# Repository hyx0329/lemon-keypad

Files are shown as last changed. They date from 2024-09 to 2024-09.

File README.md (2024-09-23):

# Lemon Keypad

> [English](README.md), [简体中文](README.zh.md)

A macro pad/mechanical keyboard based on RP2040. This is *probably* an *improved* version of the [original adafruit version](https://learn.adafruit.com/qtpy-lemon-mechanical-keypad-macropad/).

This is a simple 6-key keypad. What makes it different is that the main program is written in async Python(CircuitPython).
With python's flexibility, a lot can be done with ease with this keypad, on demand.

<!-- TOC depthfrom:2 -->

- [Project folders and their content](#project-folders-and-their-content)
- [Software implementation](#software-implementation)
    - [implemented](#implemented)
    - [potentials left to users](#potentials-left-to-users)
- [Hardware components](#hardware-components)
- [The real thing: close looks](#the-real-thing-close-looks)

<!-- /TOC -->

This repo consists of shell CAD(FreeCAD & STL), PCB design files(KiCAD), and software(CircuitPython project).

I found myself lack the capability/motivation to productize it, so I decided to publish it and hope it last longer, inspiring others.

## Project folders and their content

- CAD: stores CAD files for shell
- lemon-rp2040-keypad: kicad project file
- software: CircuitPython project directory

## Software implementation

### implemented

- keyboard keys input
    - including consumer control keys
- mouse input
- complex key actions
    - key combinations
    - key sequences
    - tap dance
    - layer switch
    - delay
- custom function
    - gyro mouse(built-in example)
    - level gauge(built-in example)

### potentials left to users

- random number generator
- Whack-a-Mole
- a BIG button used up-side-down
- password storage(with pin protection)
- ducky pad
- etc.

## Hardware components

- RP2040
- LSM6DS3TRC inertial module(gyro & accelerometer)
- WS2812 * 6
- MX switch hot-swappable socket
- Kailh BOX white switches
- WB25Q128JVSQ flash memory
- AMS1117-3V3
- misc passive components

## The real thing: close looks

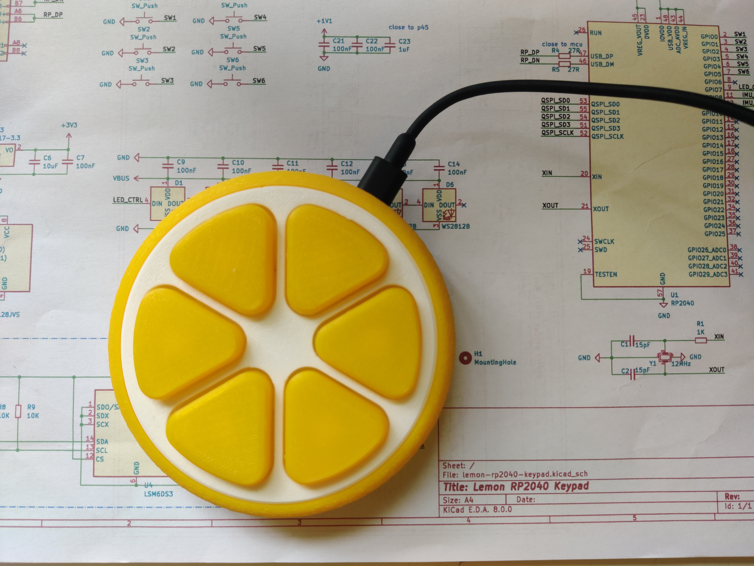
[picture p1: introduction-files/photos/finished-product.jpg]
Finished lemon keypad


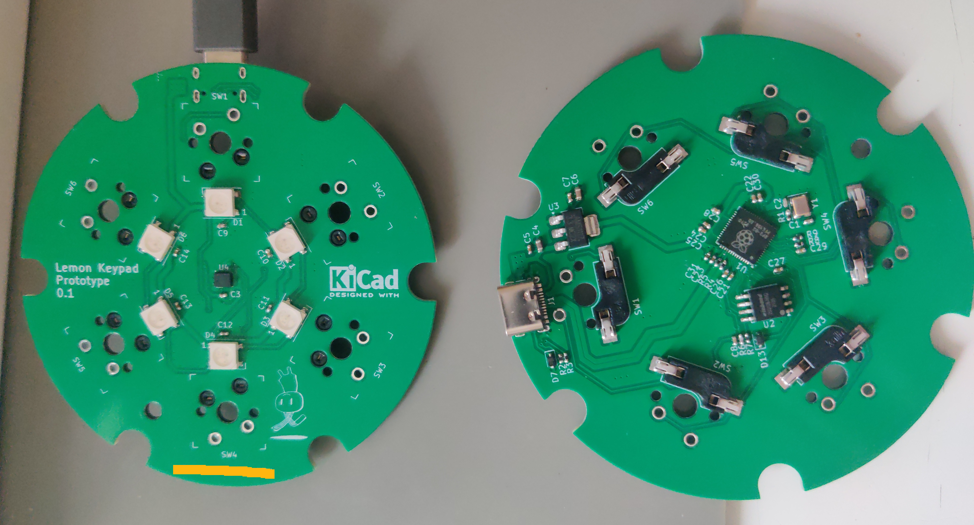
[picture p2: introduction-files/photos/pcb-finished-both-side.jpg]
PCB photos, both sides


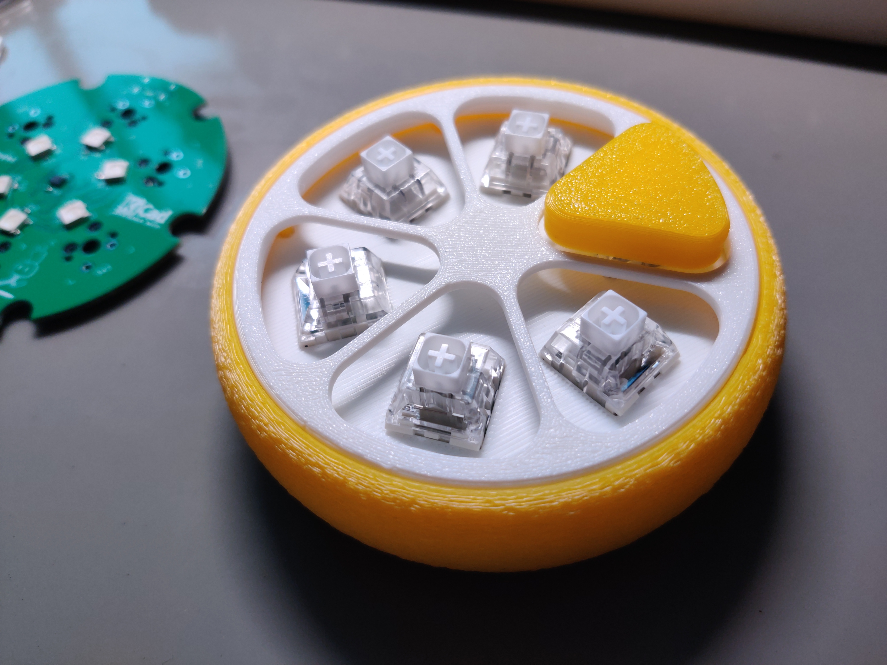
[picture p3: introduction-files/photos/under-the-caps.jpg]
under the key caps


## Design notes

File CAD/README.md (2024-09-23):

## Shell CAD

The design is remixed from the original adafruit version. What reused are:

- key switch layout
- key cap

What modified/redesigned are:

- main body
    - make it a one-piece object for easier 3D printing and assembling
    - adapt to custom PCB shape
- plates

*WARNING: If you want to replicate my work, use the STL models(tested), NOT the FreeCAD file! They may not synchronized!*

## Assembly notes

- The PCB is mounted with one optional M3 screw.
- The switch plate is secured by those MX switches.
- The top plate is secured through interference fit.

## 3D view

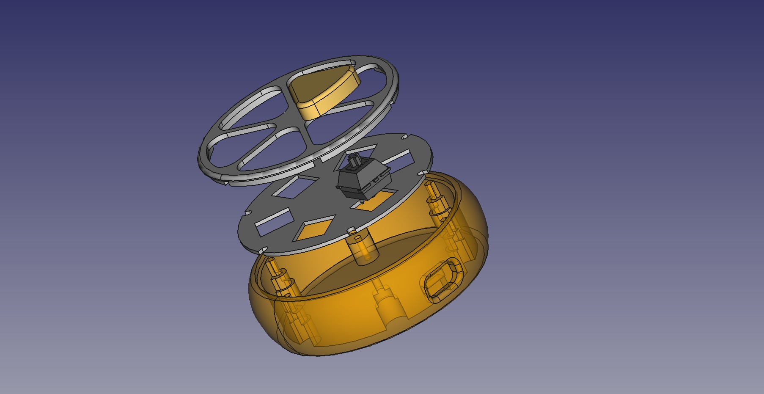
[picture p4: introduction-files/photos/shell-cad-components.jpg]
shell components, PCB not shown


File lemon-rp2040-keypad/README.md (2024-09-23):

# Lemmon Keypad KiCAD Project

Have fun! :D It's just a prototype and design issues may exist, despite I did verify the design with the real thing.

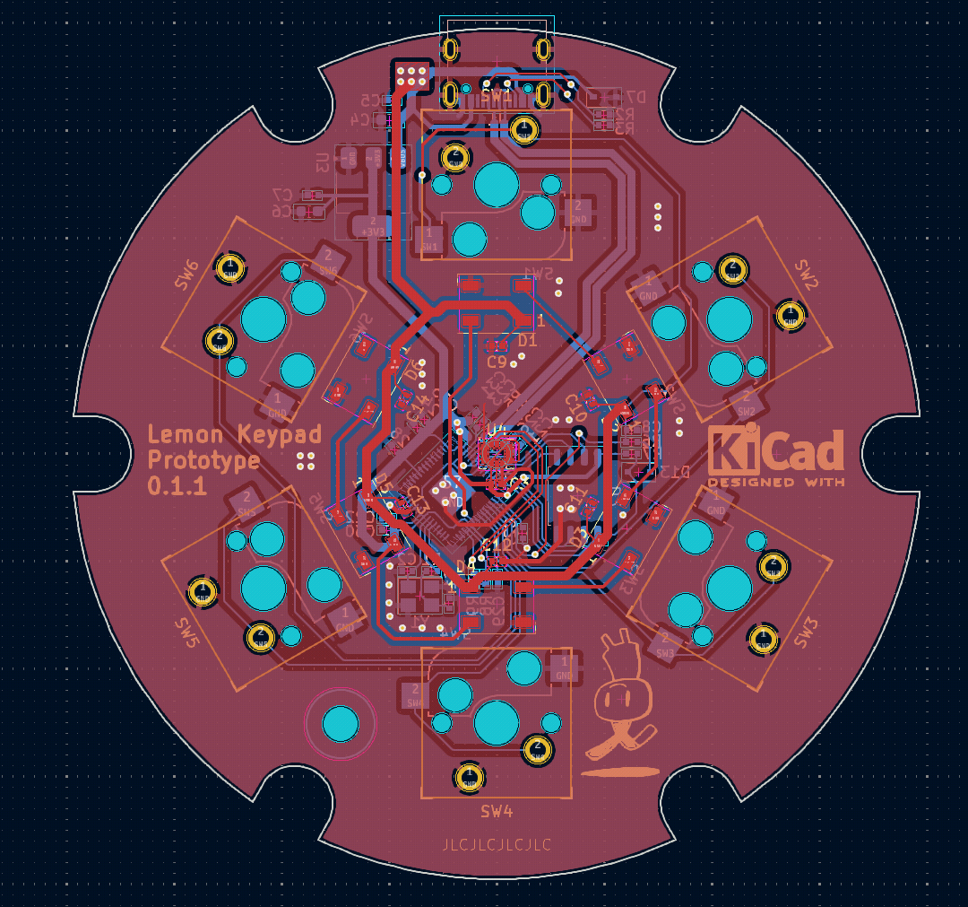
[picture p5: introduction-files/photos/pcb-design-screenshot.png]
pcb design screenshot


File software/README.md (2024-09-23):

# Software part for lemon keypad

Here is the program for lemon keypad running on top the CircuitPython firmware.

Using any Pico compatible cpy firmware variant is OK.

Aha! It's not KMK, but an original multi-layer keyboard implementation :D

## Quick package deploy

1. Install circup and ensure a good internet connection
2. Run the script with target folder as parameter: `./scripts/distribute.sh distribution`

Then the full distributable program package is the `distribution` folder.

## User documentation

Currently only zh-cn available.

## Possible flaws

- Not support key matrix natively, for it's using keypad directly without a mapping matrix.
  But it should be easy to implement.
- Not support bluetooth hid interface, need bt hid wrapper.
- Part of multi-layer support is not designed to be robust/not fully tested,
  so it may be not stable with too many/particular layer switch.

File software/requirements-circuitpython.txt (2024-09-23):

# for CircuitPython only
neopixel
adafruit_hid
adafruit_logging
asyncio
adafruit_lsm6ds

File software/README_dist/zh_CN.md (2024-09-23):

# Hi~ 你收到了一个柠檬键盘！

这份文档将介绍柠檬键盘的预装功能和修改方法。在通读这份文档后，你应该就明白如何进入安全模式、解除模拟U盘写保护，进而修改键盘功能了。

为什么默认加写保护？这不得防止杀毒软件把程序删光了。

还是建议先备份一下程序。

## 键盘硬件简介

这个设备是一个基于RP2040开发的可编程键盘。预装功能的介绍见下一节。

- 固件基于CircuitPython
    - 预载了一份功能完善的实例程序
- 硬件组件包括：
    - 树莓派RP2040微处理器（MCU，或者说CPU）
    - 6个WS2812全彩LED
    - 6个凯华BOX白轴（热插拔，可更换）
    - 1个LSM6DS3TRC 6轴姿态传感器（3轴陀螺仪、3轴加速计）
    - 16MB NOR Flash存储器（大概能放不少程序/文本）

可以把这个键盘当作一个宏键盘，实现各种特殊功能。程序采用Python编写，门槛较低，修改起来也很容易。

## 预装功能

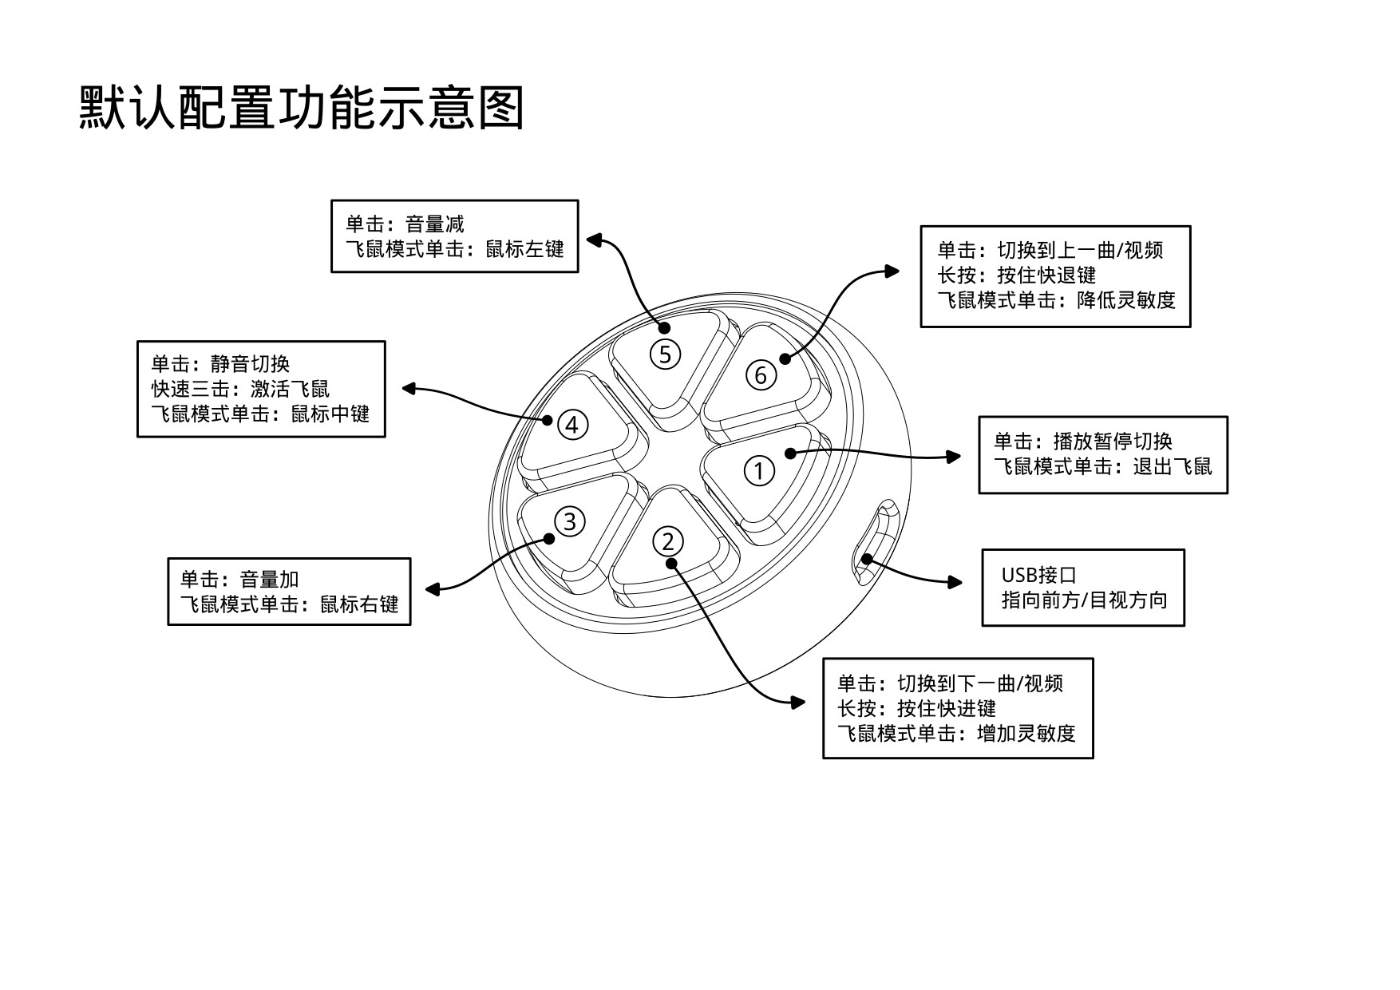
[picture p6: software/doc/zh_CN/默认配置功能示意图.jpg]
默认配置功能示意图


先说明按键顺序：USB口指向的按钮算1号，面向按钮，顺时针方向将各个按钮标记为1～6。彩色LED的编号也是如此。需要注意的是，虽然此处说明的序号从1开始，**但程序内部处理按键和LED所用的编号均从0开始**。

- 多媒体键盘，按键1到6的功能依次为：
    - 按键1：播放/暂停
    - 按键2：短按切换下一曲，长按快进
    - 按键3：音量提高
    - 按键4：静音切换，快速连按3下进入飞鼠模式
        - 飞鼠模式，单击按键1退出
        - 按键5、4、3依次为鼠标左键、中键、右键
        - 按键6、1、2依次为增加灵敏度、退出、降低灵敏度
    - 按键5：音量降低
    - 按键6：短按切换上一曲，长按快退
- 安全模式
    - 插上USB前按住除1号按钮外任意3个或以上按钮，直至所有LED显示为绿色，即进入安全模式
        - 安全模式下程序将不再运行 `boot.py`、`code.py` 中的代码，而运行 `safemode.py`。通常情况下，存放程序的模拟U盘将显示出来。
    - 安全模式为软件功能，在修改预载程序（`boot.py`和`safemode.py`）后不保证有效。
- 刷机模式
    - 按住按钮1再插上USB，可进入USB刷机模式，可以写入UF2格式的固件，一般用不到
    - 刷机模式为微处理器（RP2040）自带功能，在设备未故障时均可生效

通过修改键位图，可以按需实现多种宏功能。

- 支持多层键位图
- 支持定义点击、长按、组合键、序列按键、自定义函数等多种功能
- 放个英文字符串，能直接一口气敲出来
    - 模拟键盘采用美式布局，输出字符串其实只是自动按对应按键

## 修改功能前必读

可以先在 `code.py` 中参考示例修改键位图。亦可依次参考 `键位图示例` 文件夹中的3种键位图配置示例。预先整理好的普通键码可以在 `lib/lemon_keypad/keycode_helper.py` 中查找。按键功能类型可参阅 `软件详细说明/按键功能类型.md`，那是一个Markdown格式的普通文本文件（txt）。

`settings.toml` 是一个全局配置文件，支持字符串作为键、字符串或整数为值，其中的值可采用 `os.getenv("key_name")` 的方法获取。预装配置里提供了配置示范、记录了IMU加速度补偿值。

## 深度修改提示

在做出较复杂的修改前，建议先阅读 `boot.py`、`code.py`、`safemode.py` 程序文件，全部的键位图示例，了解键盘主程序的基本设计。

## 参考点子

- （伪）随机数生成器（也确实有办法做成真随机，参考pico-rng）
- 水平仪（用姿态传感器检测，LED指示偏移方向，这个功能已预装）
- 密码存储器
- 一键搓招，需要自己添加对gamepad的支持
- 一键脚本注入
- 普通的媒体控制器
- 某种惯导鼠标
- 打地鼠游戏机
- 功德木鱼（还是算了）
- 反过来当单个大号按键？（毕竟有姿态传感器，能做到自动切换）

## CircuitPython程序运行流程

每次启动时，CircuitPython会初始化Python解释器环境，在普通模式下执行`boot.py`，然后执行`code.py`。在因意外发生或人为切换进入到安全模式时，解释器不会执行`boot.py`和`code.py`，而是执行`safeboot.py`（如果存在）。

默认情况下，CircuitPython会提供一个USB模拟串口（Windows上的COM端口），用于数据交互/用户控制。用户打开串口（波特率115200）时可以传入Ctrl+C终止当前运行的程序。这个串口也可以被用户关闭，此处不表，参阅`boot.py`。

每次解释器环境重置时，绝大多数硬件资源将被释放，随后重置为初始状态。相当于重开了个Python解释器。

程序的默认工作目录是 `/`，即模拟U盘的根目录。解释器也会尝试从 `/lib` 加载所需python模块。

## 固件更新

细心的朋友可能会发现，本设备用的CircuitPython是给别的RP2040开发板用的。RP2040的CircuitPython固件大多互相兼容，主要是 `board` 模块暴露的引脚（GPIO）略有不同。

想升级固件，可以下载[WeAct Pico 16MB的UF2固件](https://circuitpython.org/board/weact_studio_pico_16mb/)，将设备切换至刷机模式，然后将UF2固件拖入模拟U盘中完成更新。

注意，跨大版本更新会导致程序无法运行。如需要跨大版本更新，请同时更新 `/lib` 中的CircuitPython模块，此处不详叙。程序直接依赖的模块记录在 `requirements-circuitpython.txt` 文件中。柠檬键盘预装CircuitPython 9.x，大版本为9的固件都可以兼容预装程序。

## 拆解方法

先取下键帽，再扣下顶盖，随后依次移除键盘轴、定位板、PCB主板。务必注意，PCB主板上可能有一颗M3螺丝，而部分版本的PCB与外壳之间的配合非常紧密（难拆），请小心操作，可以在卸下螺丝后用钩状工具辅助拆解。整体螺丝数量不多于1。

## 最后补充说明

想解除U盘写保护，只要进入安全模式、删除 `lock_usb_drive.txt` 文件即可。具体程序的实现在 `boot.py` 文件的末尾。

如果你确定自己完全理解了这份文档，可以考虑在模拟U盘中创建 `disable_usb_drive.txt` 文件，以隐藏模拟U盘，让这个键盘更像普通的键盘。这个功能由 `boot.py` 实现，所以要是改了可能就不管用了。**进入安全模式可以临时让这个模拟U盘变回来。**

如果魔改固件发现锁死了、无法打开串口终端、无法恢复的话，可能要进刷机模式刷清空专用固件、再重刷CircuitPython固件、将程序复制进去了。

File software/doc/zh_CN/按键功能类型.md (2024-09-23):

# 按键功能类型说明

*本文档可能和实际代码有一定不同，提供此文档仅供功能参考，实际以代码实现为准*

在键位图中填写的按键功能分两大类

- 可直接执行的按键功能
    - 键盘、鼠标、多媒体按键
    - 用户函数
    - 字符串输出
    - 按键序列
    - 按键组合
    - 时延（一段时间什么都不做）
- 暂时不能确定的按键功能
    - 复合按键
        - 触发方式包括短按、长按、超长按，判定方法有二
            - 根据按键按下时间长度判定（复合按键抬起）
            - 根据新按键按下的时间与复合按键按下的时间差判定（复合按键没抬起，新按键按下）
        - 触发的功能包括短按、长按、键位图层切换、超长按
            - 其中长按与键位图层
    - 连击按键，按键功能由连击次数决定，触发判定的机制有三
        - 有新的不同按键在动作中按下
            - 立刻触发按键次数对应的按键功能
        - 从按下开始计算，在限时内没有再按下一次
            - 按住也算没有再按下一次
            - 触发第“按键次数”的功能
        - 按的次数太多，达到了备选键列表的长度
            - 直接触发最后一个设置的功能

## 可直接执行的按键功能

### 键盘、鼠标、多媒体按键

在键位图中，键盘、鼠标、多媒体按键都是int数字，与HID报文中的值对应，故在此称之为键码。不过为了区分三类键码，鼠标和多媒体按键均用继承自int类型的对应类来表示。

- 键盘键码：int类型，直接从键盘HID接口发出
- 鼠标键码：MouseCode(int)类型，直接从鼠标HID接口发出
- 多媒体键码：ConsumerCode(int)类型，直接从多媒体HID接口发出

### 用户函数

用户定义的函数可以作为按键功能填入键位图。这个函数可以是普通函数也可以是异步函数。程序内处理的流程如下：

1. 检查按键功能是否可以执行（callable），如是，执行，取返回值result
2. 检查返回值是否是coroutine对象，如是，await，取返回值result
3. 在日志中输出result

用户定义的函数可能会抛出异常，键盘程序将检测并在日志中记录此异常，程序不会崩溃。

用户定义函数将接受一个值为当前键盘主程序实例的参数，以便执行特殊动作。

考虑到用户函数有阻塞、死锁的可能，间接影响其它可能并发执行的函数，建议用户使用异步函数，并不时调用 `await asyncio.sleep(0)` 来切换任务。在启用看门狗计时器时，务必注意避免阻塞，及时喂狗。

在执行用户函数前后，会重置下列状态：

- 所有按键状况，全部按键将抬起
- 键位图层状态，将重置到默认层

### 字符串输出

用户可以将字符串填入键位图作为按键功能，其中的ASCII字符将转换为对应的键盘键码直接发出。

此实现不保证字符串输出时的准确性，因为键码与字符的对应关系可能因系统键盘布局产生差异。键盘程序采用了美式QWERTY键盘布局。

在字符串输出前后，所有HID输出的按键均将重置为松开状态松开。

### 按键序列

若以按键序列为按键动作，那么按键序列中的每个键将被依次按下、抬起。也可以视为一种字符串输出方式，不过设计组合键更方便。

此实现支持与自己或按键组合嵌套。

### 按键组合

若以按键组合为按键动作，键盘程序将依次连续按下各个按键，再连续依次抬起各个按键。需要注意，键盘HID报文采用6KRO格式，最多支持同时按下6个按键。

此功能适合触发组合键，如Ctrl+Alt+Del。

此实现支持与自己或按键序列嵌套。

### 时延

就是键盘暂停执行一段时间，不执行任何动作。这个动作的参数单位是秒，可以包含小数。

## 暂时不能确定的按键功能

此类按键将在未判定时记录在临时区域，在处理下一个按键下压事件之前处理完毕。最多只会出现一个功能待定的按键。

### 复合按键

此功能主要设计用于键位图层切换。此功能可以触发下列功能：

- 单击功能（tap）
- 长按功能（hold）
- 键位图层切换（layer），与长按一同触发
- 超长按（long_hold），按得足够久就触发

如果定义了tap，则当按键按下并在 `tap_term_ms` 之前抬起，将触发单击功能。

如果定义了tap，且设置 `tap_preferred` 参数为True，则当按键按下 `tap_term_ms` 时间内被其它按键打断时，将触发单击功能。

如果定义了tap，且设置 `tap_preferred` 参数为False，则当按键按下 `tap_term_ms` 时间内被其它按键打断时，将触发长按功能。

如果未定义tap，且设置了hold或layer，则当按键按下 `hold_term_ms` 时间内被其它按键打断时，将同时触发设置的长按功能和键位图层切换功能。

当设置了超长按（long_hold）且按键时间介于 `hold_term_ms` 和 `long_hold_start_ms` 之间时，若按键功能因按键抬起或其它按键按下而触发，则将不触发任何功能

在没有设置超长按（long_hold）功能时，长按功能将在长按时触发，不受 `hold_term_ms` 参数影响。

当设置了超长按（long_hold）且按键时间超过了 `long_hold_start_ms` 时间，将立刻触发超长按功能。

在只定义了tap功能时，`tap_preferred`将自动设置为True。而在没有设置tap时，`tap_preferred`将自动设置为False。

### 连击按键

一种实际功能受连击此处影响的按键功能，国外称之为Tap Dance。

连击按键定义了一组有序按键功能，按键的次数决定了执行第几个按键功能。

当超过按键间隔限时、或是被新按键打断，将触发此刻按键次数对应的功能。
当按键次数超过定义的功能数量，将触发最后一个功能。

可以在创建该按键功能时用 `tap_term_ms` 参数调整按键间隔时限。

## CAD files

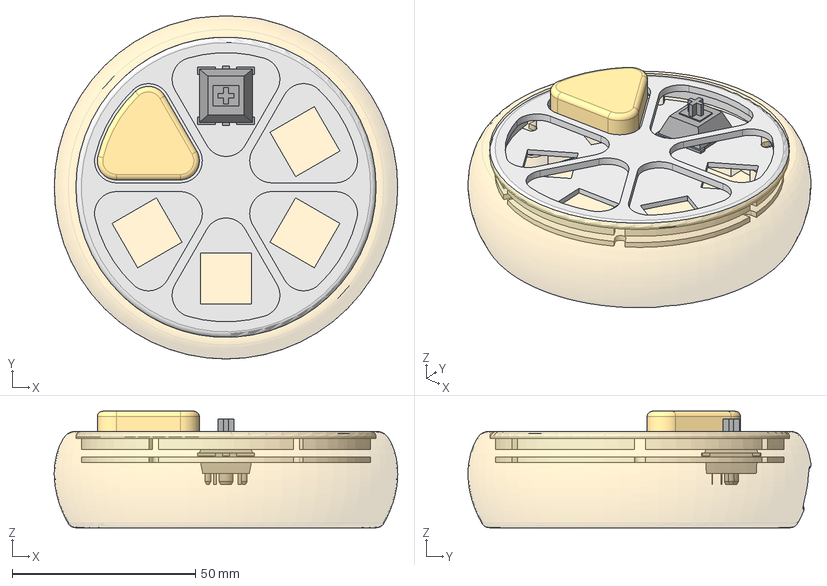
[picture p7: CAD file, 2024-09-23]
CAD/new-lemon-keypad.FCStd
93.8 x 93.7 x 31.8 mm
cherry mx v3
Cap001
top-frame
switch-frame
spherical-body001

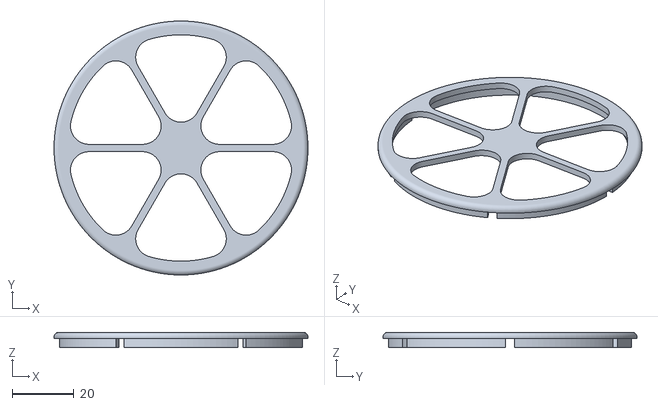
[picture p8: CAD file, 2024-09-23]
CAD/STL/top-frame-tight.stl
82.5 x 82.5 x 5.00

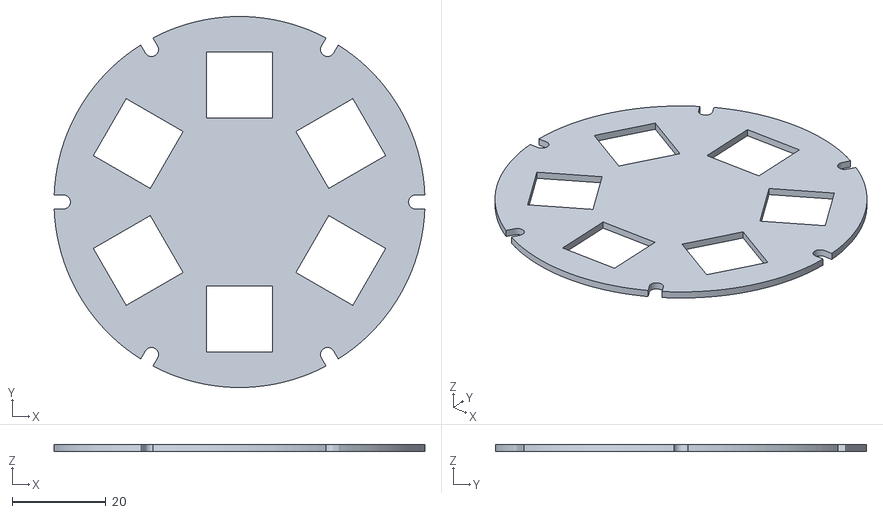
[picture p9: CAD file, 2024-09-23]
CAD/STL/switch-frame.stl
78.9 x 79.0 x 1.50

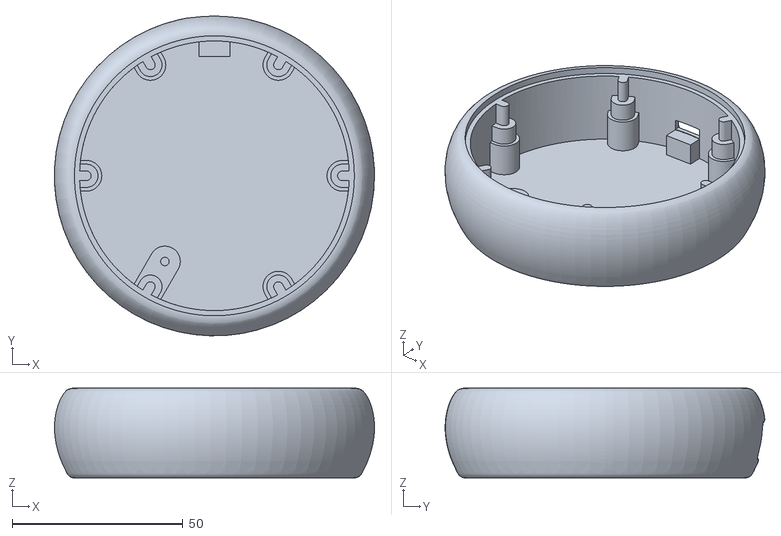
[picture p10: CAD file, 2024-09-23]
CAD/STL/spherical-body-tight-do-not-use.stl
93.8 x 93.7 x 26.3

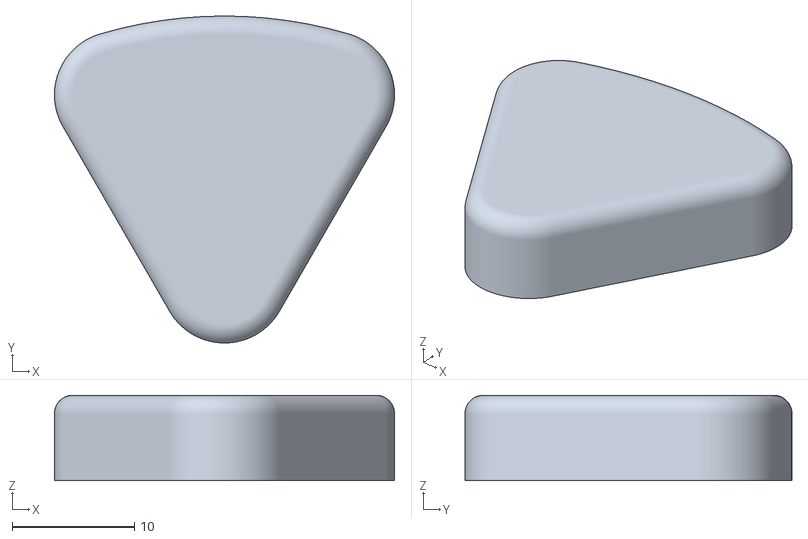
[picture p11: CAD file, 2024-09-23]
CAD/STL/cap.stl
27.9 x 26.8 x 7.00

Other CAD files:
CAD/STL/spherical-body-loose3.stl

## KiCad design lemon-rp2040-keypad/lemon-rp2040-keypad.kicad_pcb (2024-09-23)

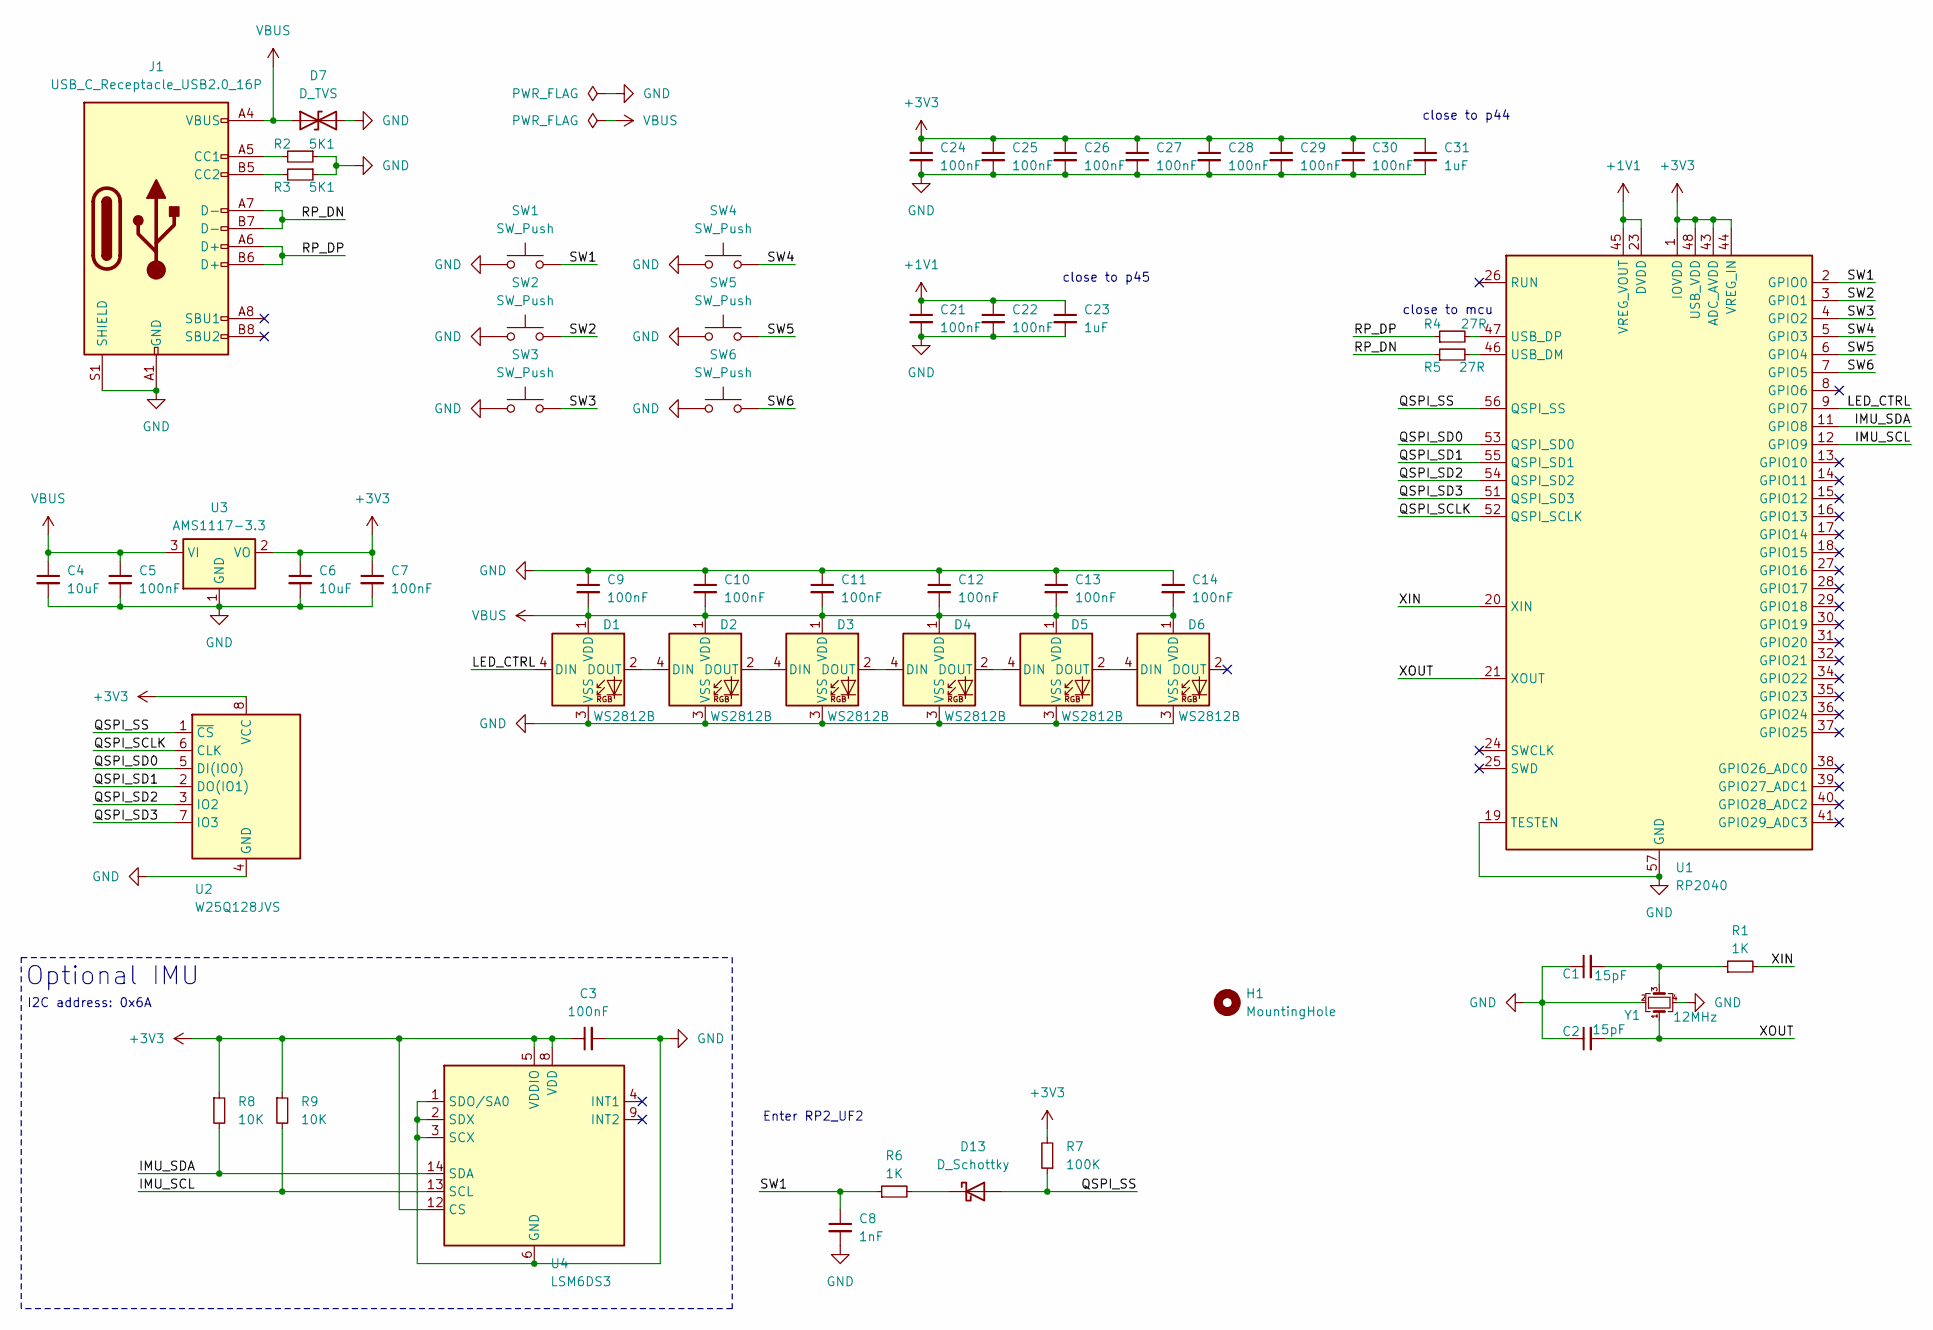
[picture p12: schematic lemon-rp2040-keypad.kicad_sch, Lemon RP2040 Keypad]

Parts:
C1, C2: 15pF; C_0402_1005Metric
C3, C5, C7, C9, C10, C11, C12, C13, C14, C21, C22, C24, C25, C26, C27, C28, C29, C30: 100nF; C_0402_1005Metric
C4, C6: 10uF; C_0603_1608Metric
C8: 1nF; C_0402_1005Metric
C23, C31: 1uF; C_0402_1005Metric
D1, D2, D3, D4, D5, D6: WS2812B; LED_WS2812B_PLCC4_5.0x5.0mm_P3.2mm
D7: D_TVS; D_SOD-323
D13: D_Schottky; D_SOD-323
H1: MountingHole; MountingHole_3.2mm_M3
J1: USB_C_Receptacle_USB2.0_16P; USB_C_Receptacle_G-Switch_GT-USB-7010ASV
R1, R6: 1K; R_0402_1005Metric
R2, R3: 5K1; R_0402_1005Metric
R4, R5: 27R; R_0402_1005Metric
R7: 100K; R_0402_1005Metric
R8, R9: 10K; R_0402_1005Metric
SW1, SW2, SW3, SW4, SW5, SW6: SW_Push; Kailh_socket_MX_optional
U1: RP2040; QFN-56-1EP_7x7mm_P0.4mm_EP3.2x3.2mm
U2: W25Q128JVS; SOIC-8_5.23x5.23mm_P1.27mm
U3: AMS1117-3.3; SOT-223-3_TabPin2
U4: LSM6DS3; LGA-14_3x2.5mm_P0.5mm_LayoutBorder3x4y
Y1: 12MHz; Crystal_SMD_3225-4Pin_3.2x2.5mm

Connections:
+1V1: C21.1, C22.1, C23.1, U1.23 (DVDD), U1.45 (VREG_VOUT), U1.50 (DVDD)
+3V3: C3.1, C6.1, C7.1, C24.1, C25.1, C26.1, C27.1, C28.1, C29.1, C30.1, C31.1, R7.2, R8.1, R9.1, U1.1 (IOVDD), U1.10 (IOVDD), U1.22 (IOVDD), U1.33 (IOVDD), U1.42 (IOVDD), U1.43 (ADC_AVDD), U1.44 (VREG_IN), U1.48 (USB_VDD), U1.49 (IOVDD), U2.8 (VCC), U3.2 (VO), U4.5 (VDDIO), U4.8 (VDD), U4.12 (CS)
/IMU_SCL: R9.2, U1.12 (GPIO9), U4.13 (SCL)
/IMU_SDA: R8.2, U1.11 (GPIO8), U4.14 (SDA)
/LED_CTRL: D1.4 (DIN), U1.9 (GPIO7)
/QSPI_SCLK: U1.52 (QSPI_SCLK), U2.6 (CLK)
/QSPI_SD0: U1.53 (QSPI_SD0), U2.5 (DI(IO0))
/QSPI_SD1: U1.55 (QSPI_SD1), U2.2 (DO(IO1))
/QSPI_SD2: U1.54 (QSPI_SD2), U2.3 (IO2)
/QSPI_SD3: U1.51 (QSPI_SD3), U2.7 (IO3)
/QSPI_SS: D13.2 (A), R7.1, U1.56 (QSPI_SS), U2.1 (~CS)
/RP_DN: J1.A7 (D-), J1.B7 (D-), R5.1
/RP_DP: J1.A6 (D+), J1.B6 (D+), R4.1
/SW1: C8.1, R6.1, SW1.1, U1.2 (GPIO0)
/SW2: SW2.2, U1.3 (GPIO1)
/SW3: SW3.2, U1.4 (GPIO2)
/SW4: SW4.2, U1.5 (GPIO3)
/SW5: SW5.2, U1.6 (GPIO4)
/SW6: SW6.2, U1.7 (GPIO5)
/XIN: R1.2, U1.20 (XIN)
/XOUT: C2.2, U1.21 (XOUT), Y1.1
GND: C1.1, C2.1, C3.2, C4.2, C5.2, C6.2, C7.2, C8.2, C9.1, C10.1, C11.1, C12.1, C13.1, C14.1, C21.2, C22.2, C23.2, C24.2, C25.2, C26.2, C27.2, C28.2, C29.2, C30.2, C31.2, D1.3 (VSS), D2.3 (VSS), D3.3 (VSS), D4.3 (VSS), D5.3 (VSS), D6.3 (VSS), D7.2 (A2), J1.A1 (GND), J1.A12 (GND), J1.B1 (GND), J1.B12 (GND), J1.S1 (SHIELD), R2.1, R3.1, SW1.2, SW2.1, SW3.1, SW4.1, SW5.1, SW6.1, U1.19 (TESTEN), U1.57 (GND), U2.4 (GND), U3.1 (GND), U4.1 (SDO/SA0), U4.2 (SDX), U4.3 (SCX), U4.6 (GND), U4.7 (GND), Y1.2, Y1.4
unnamed: C1.2, R1.1, Y1.3
unnamed: D1.2 (DOUT), D2.4 (DIN)
unnamed: D2.2 (DOUT), D3.4 (DIN)
unnamed: D3.2 (DOUT), D4.4 (DIN)
unnamed: D4.2 (DOUT), D5.4 (DIN)
unnamed: D5.2 (DOUT), D6.4 (DIN)
unnamed: D13.1 (K), R6.2
unnamed: J1.A5 (CC1), R2.2
unnamed: J1.B5 (CC2), R3.2
unnamed: R5.2, U1.46 (USB_DM)
unnamed: R4.2, U1.47 (USB_DP)
VBUS: C4.1, C5.1, C9.2, C10.2, C11.2, C12.2, C13.2, C14.2, D1.1 (VDD), D2.1 (VDD), D3.1 (VDD), D4.1 (VDD), D5.1 (VDD), D6.1 (VDD), D7.1 (A1), J1.A4 (VBUS), J1.A9 (VBUS), J1.B4 (VBUS), J1.B9 (VBUS), U3.3 (VI)

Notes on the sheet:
Enter RP2_UF2
close to mcu
I2C address: 0x6A
close to p45
Optional IMU
close to p44

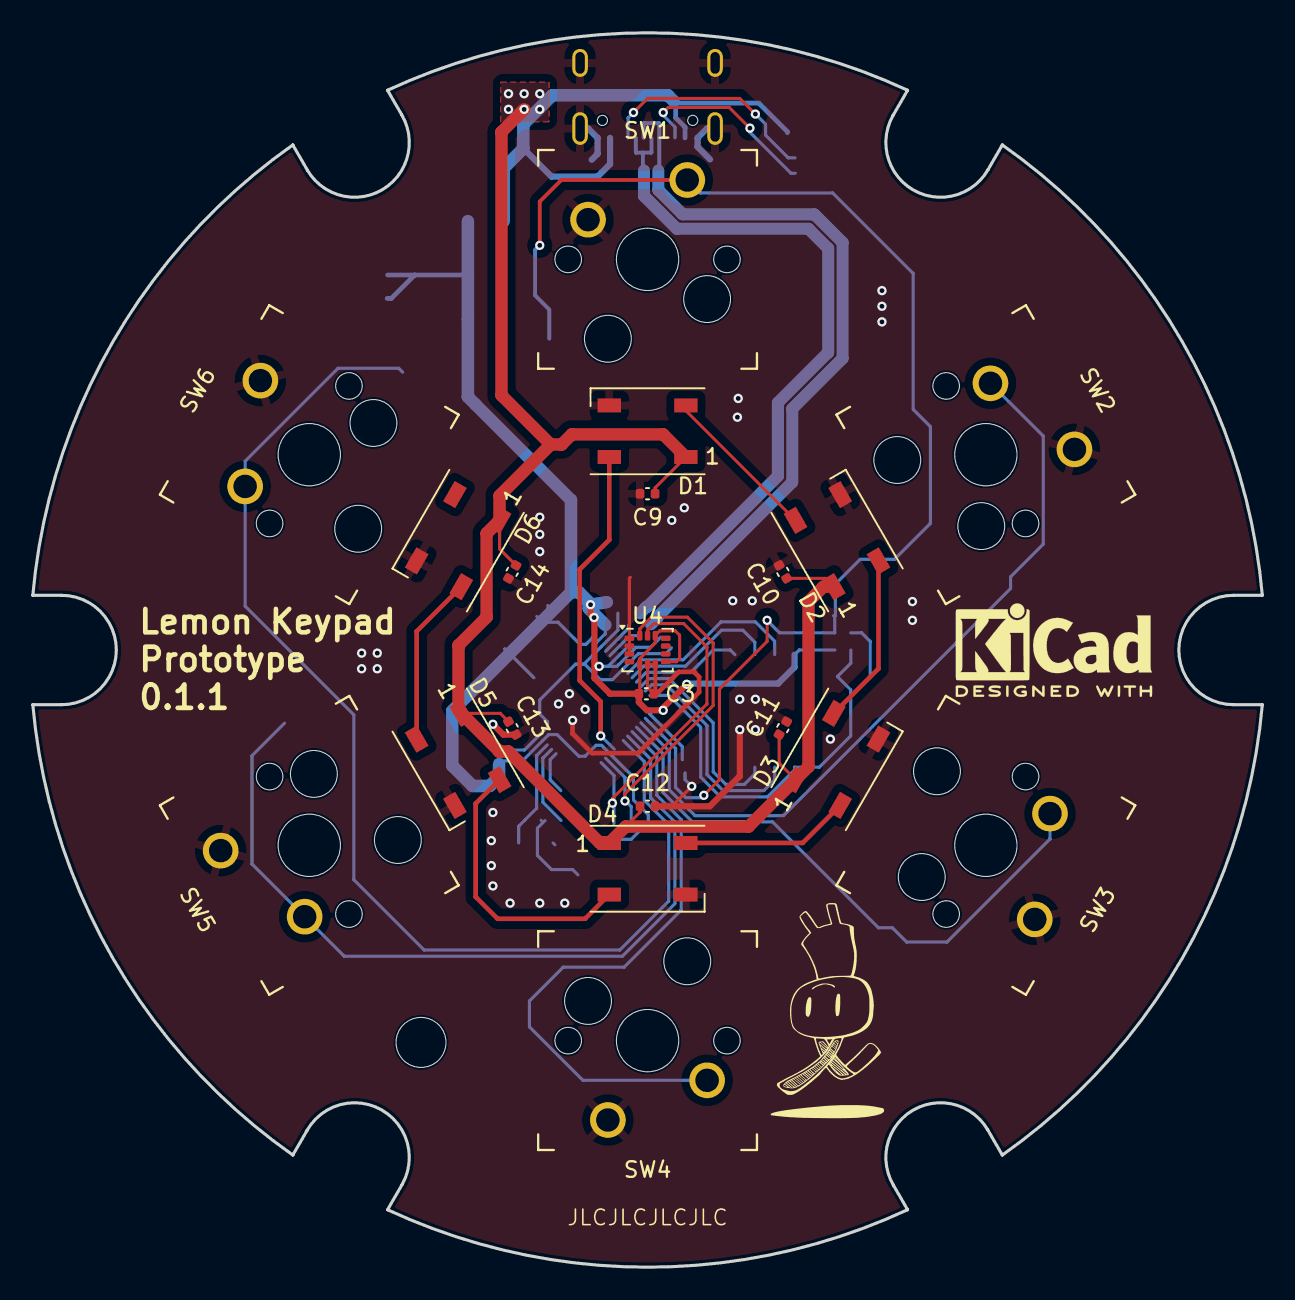
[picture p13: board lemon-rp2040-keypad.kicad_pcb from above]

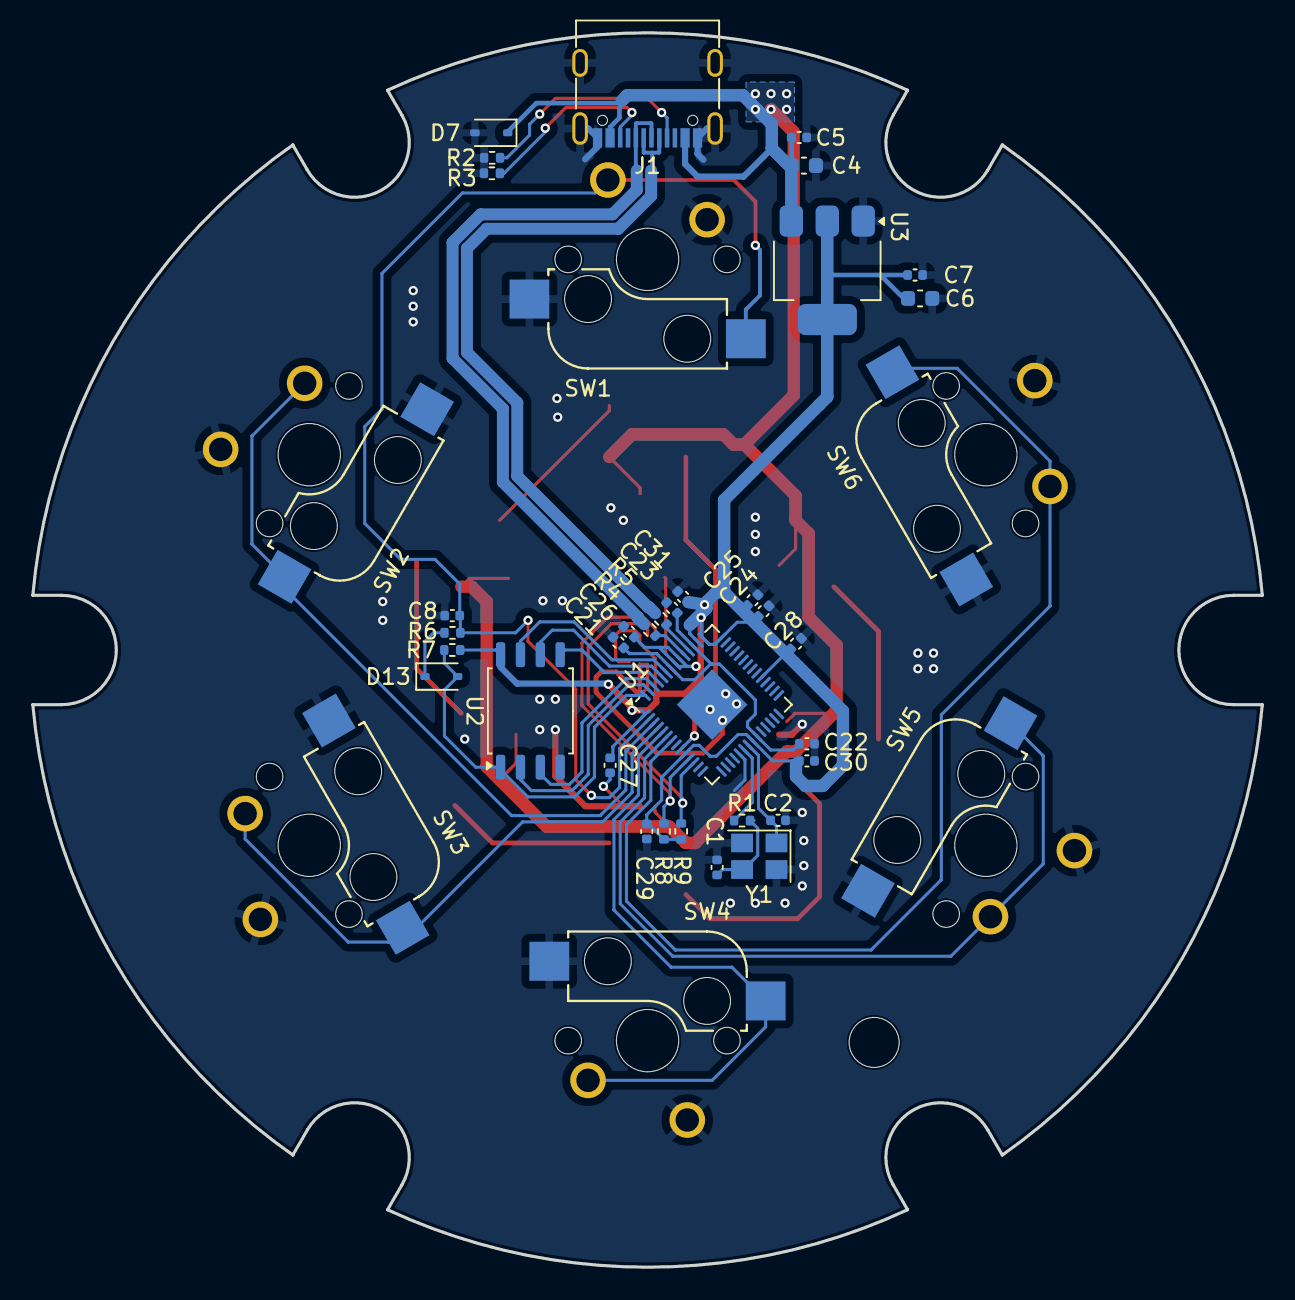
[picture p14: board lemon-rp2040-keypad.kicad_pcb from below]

Board: 2 copper layers, 78.7 x 79.0 mm, 55 parts (34 on the bottom side), 34 nets.

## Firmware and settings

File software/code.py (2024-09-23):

import board
from busio import I2C

from neopixel import NeoPixel
from adafruit_lsm6ds.lsm6ds3trc import LSM6DS3TRC

from adafruit_hid.consumer_control_code import ConsumerControlCode
from adafruit_hid.keycode import Keycode


# board consts
I2C_SCL = board.GP9
I2C_SDA = board.GP8
PIXEL_PIN = board.GP7
BUTTON_PINS = [board.GP0, board.GP1, board.GP2, board.GP3, board.GP4, board.GP5]

# initialize hardware except buttons/keys
pixels = NeoPixel(PIXEL_PIN, 6)
pixels.fill((0, 0, 0))
i2c = I2C(I2C_SCL, I2C_SDA)
imu = LSM6DS3TRC(i2c, 0x6a)

# Pull code for lemon keypad
from lemon_keypad import LemonKeypad
from lemon_keypad import CompositeAction as Act
from lemon_keypad import ConsumerCode as CC
from lemon_keypad import KeySequence as KS
from lemon_keypad import KeyCombination as KC
from lemon_keypad import TapDance as TD
from lemon_keypad.keycode_helper import *
# from lemon_keypad.playground.level_gauge import level_gauge
from lemon_keypad.playground.gyro_mouse import gyro_mouse

# basic keypad configuration
keypad = LemonKeypad()
keypad.keys = BUTTON_PINS
keypad.key_active_value = False  # all pins are low active
keypad.imu = imu
keypad.pixels = pixels

# verbose logging
keypad.debug = True

# well you CAN change the default keymap layer id
# but make sure it exists
#keypad.default_layer = 0

# enable watchdog if you'd like to
# MCU will reset itself if watchdog timed out
#keypad.enable_watchdog()

# Your key map
# The default keymap is indexed as "0"(integer)(yet can be changed)
# key actions:
# - integer: raw keyboard keycode sent though keyboard hid interface
# - string: text sent though keyboard hid interface
# - Mouse(int): mouse buttons
# - ConsumerCode(int): consumer control key(aka. media key, like MUTE, PAUSE)
# - KeySequence(*): sequence of keys/actions to perform
# - KeyCombination(*): combination of keys/actions to perform
# - TapDance(*): tap to determine which key/action to perform
keymap = {
    0: [
        C_PLAY_PAUSE,
        Act(C_SCAN_NEXT_TRACK, C_FAST_FORWARD),
        C_VOLUME_INCREMENT,
        TD(C_MUTE, None, gyro_mouse),
        C_VOLUME_DECREMENT,
        Act(C_SCAN_PREVIOUS_TRACK, C_REWIND),
    ],
}

# set keymap
keypad.keymap = keymap

keypad.run()

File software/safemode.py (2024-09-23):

import board
import neopixel
import storage
import os

pixel_pin = board.GP7
num_pixels = 6


# load neopixel and set all led to green to indicate that it's safe mode.
color = (0, 0x20, 0)
pixels = neopixel.NeoPixel(pixel_pin, num_pixels)

pixels.fill(color)

# change drive label, up to 11 chars
DRIVE_LABEL = os.getenv('drive_label')
if DRIVE_LABEL is None:
	DRIVE_LABEL = "LEMONKEYPAD"
if DRIVE_LABEL != storage.getmount("/").label:
	storage.remount("/", readonly=False)
	m = storage.getmount("/")
	m.label = DRIVE_LABEL
	storage.remount("/", readonly=True)

# Remount USB drive to make sure it's writable by host.
# Actually this is not necessary.
# If USB drive is read-only when in safemode, run a partition check and fix the errors.
storage.remount('/', readonly=True)  # This means read-only by CircuitPython and read-write by host.
